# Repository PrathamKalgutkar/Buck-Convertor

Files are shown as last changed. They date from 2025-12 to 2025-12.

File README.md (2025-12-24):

Buck Convertor designed for IIT Madras's EE4102 - "Electronic Product Design" Course Project
Contained in the Repository are the KiCAD project Files, CSV file for Bill of Materials and PDF File of Final Report submitted to Course Instructor

The Project consisted of :
- Design of Buck Convertor
- Derivation of Component Values
- Design of Circuit Schematic
- Design of DRC checked PCB Board
- 3D View of the Designed PCB
- Estimation of Convertor Efficiency
- Bill of Materials

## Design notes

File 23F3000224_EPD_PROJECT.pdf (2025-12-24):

# ELECTRONIC PRODUCT DESIGN PROJECT

PRATHAM SANJEEV KALGUTKAR

23F3000224

### - Design a circuit with input 24 V DC (Assume a 24 battery) and output of +15V and 0.5 A

For the given design requirements, A buck convertor is ideal for this application, moreover, we will be using a “Jellybean”, a Widely Available and Affordable Convertor, for the design. Texas Instruments, MC34063 is ideal for our use case

Design Requirements: - Referencing the Chapter 9.2.3.1 of the Datasheet, we need to define certain design requirements given below

Vin = 24V

Vout = 15V

Iout(Max) = 0.5A

fmin = 100 kHz (Maximum Switching Frequency, refer 8.3, taken to reduce Component Values)

Vripple = ±100mV (Peak to Peak Value of desired Ripple)

Vsat = 1V (Refer 7.6 For Saturation Voltage of Darlington pair)

Vf = 0.4V (Refer Figure 13 of Diode 1N5819)

R1 = 1000 Ω

R2 = 11000Ω

Design Procedure: - Referencing Table 9.2.3.2, we need to calculate various parameters to determine the component Values

ton

toff

=

Vout + Vf

Vin(Min) − VSat − VOut

=

15 + 0.4
24 − 1 − 15 =

77
40

= 1.925

(ton + toff) =

1
f

=

1
100000 = 1 × 10⁻⁵
sec

toff =

ton + toff
ton
toff

+ 1

=

1 × 10⁻⁵
1.925 + 1

=

1
292500 = 3.418803419 × 10⁻⁶ sec

ton = (ton + toff) − toff = 1 × 10⁻⁵ −

1
292500 = 6.581196581 × 10⁻⁶

CT = 4 × 10⁻⁵

ton = 2.6323478632 × 10⁻¹⁰ F ≈ 270pF

Ipk(Switcℎ) = 2 × Iout(Max) = 2 ∗ 0.5 = 1A

Rsc =

0.3

Ipk(Switcℎ)

= 0.3 Ω

LMin = (
Vin(Min) − Vsat − Vout

Ipk(switcℎ)

) tonmax = (
24 − 1 − 15
1

) ∗ 6.581196581 × 10⁻⁶

= 5.264957265 × 10⁻⁵ ≈ 52μH ≈ 68μH (Next standard value)

Co =

Ipk(switcℎ) ∗ (ton + toff)

8Vripple(pp)

=

1 ∗ 1 × 10⁻⁵
8 ∗ 0.2

= 6.25 × 10⁻⁶ ≈ 6.8μF

Vout = 1.25 (1 +

R2
R1

) = 1.25 (1 +

11000
1000 ) = 15V

### Final Component Values

Timing Capacitor: - | CT = 270 pF
Output Capacitor: - | CO = 6.8 μF
Inductor: - | L = 68 μH
Short Circuit Resistor: - | Rsc = 0.3 Ω
Feedback Resistors: - | R1 = 1KΩ
| R2 = 11KΩ

### Schematic Diagram: -

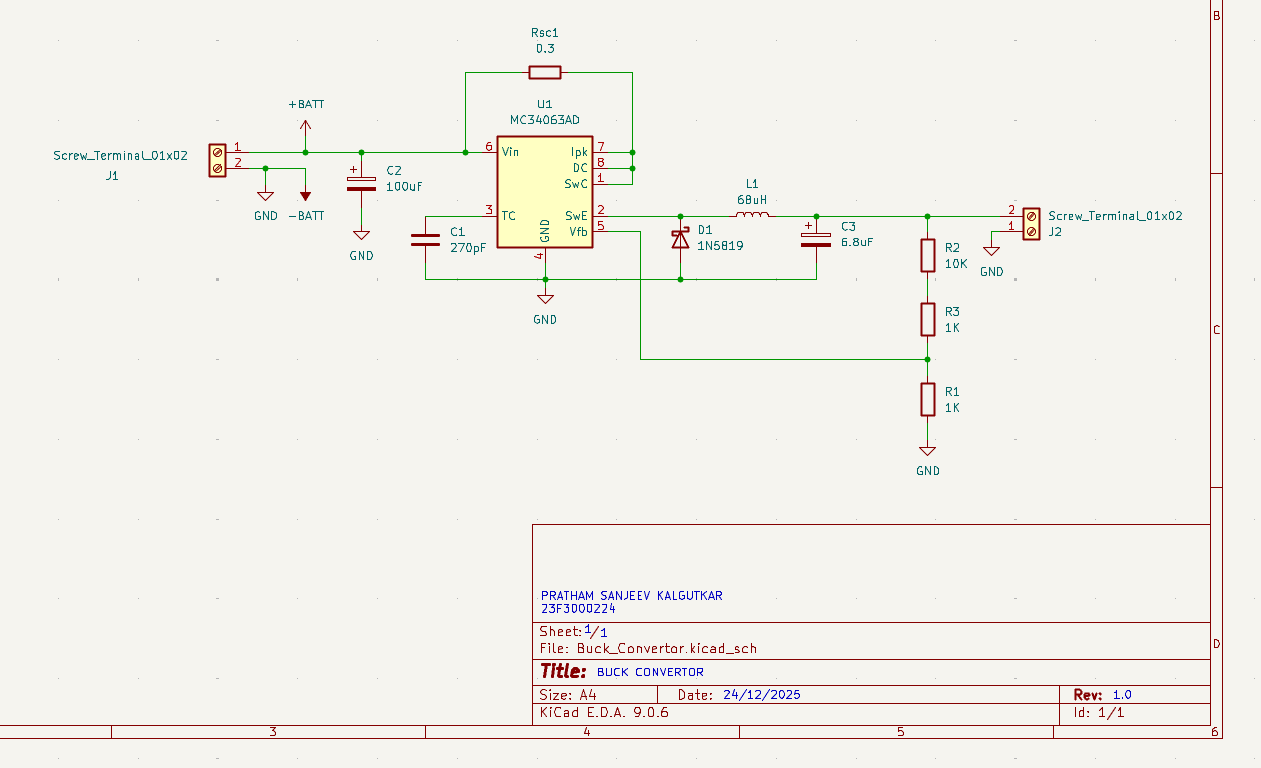
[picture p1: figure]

### PCB LAYOUT: -

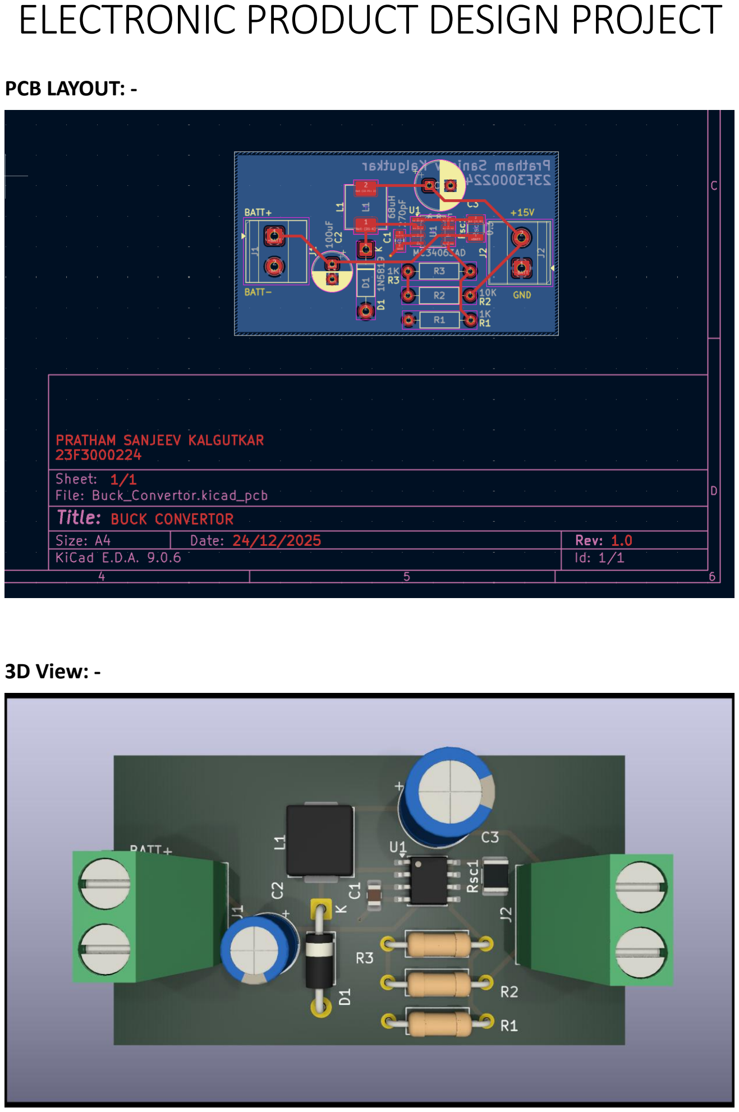
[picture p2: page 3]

### 3D View: -

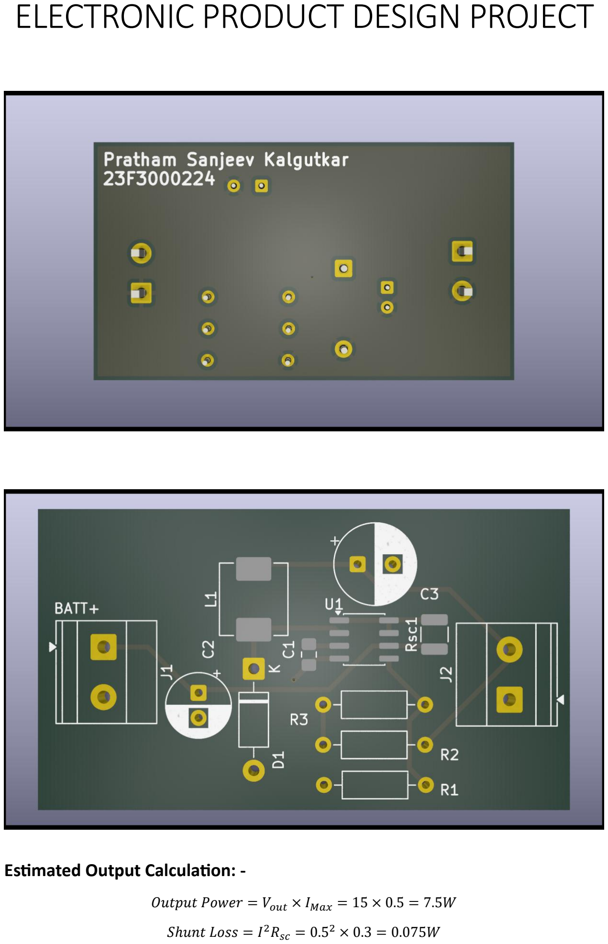
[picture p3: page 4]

### Estimated Output Calculation: -

Output Power = Vout × IMax = 15 × 0.5 = 7.5W

Sℎunt Loss = I

2Rsc = 0.5

2 × 0.3 = 0.075W

Switcℎ Conduction Loss = Iout × Vsat ×

ton
toff
ton
toff

+ 1

= 0.5 ∗ 1 ∗

1.925
1.925 + 1

=

77
234 ≈ 0.329059W

Diode Loss = Iout × Vf × (1 −

ton
toff
ton
toff

+ 1

) = 0.5 × 0.4 × (1 −
1.925
1.925 + 1

) =

6
117 ≈ 0.068W

Inductor Loss = I

2 × RDC = 0.5

2 × 0.213 = 0.05325W

Quiescent Power Draw = Vin ∗ Icc = 24 ∗ 0.004 = 0.096W

Switcℎing Loss = 0.5 × Ipk × Vin × f × trise = 0.5 × 1 × 24 × 100000 × 75ns = 0.09W

Total Loss = 0.075 +

77
234 +

6
117 + 0.05325 + 0.096 + 0.9 = 0.4558019603W

Output Power = Input Power + Total Loss = 7.5 + 0.4580419603 = 7.95580196W

Estimated Efficiency η ≈

Output Power
Input Power =

7.5
7.95580196 = 0.942708232 ≈ 94.27%

### BILL OF MATERIALS: -

# | Reference Qty Value | Datasheet Product Link | Price

1 | Rsc1 | 1 | 0.3 | ~

https://robu.in/product/0-3-ohm-3wsurface-mount-sense-resistor-pack-of-
3/#tab-description | 12
2 | R2 | 1 | 10K | ~

https://robu.in/product/10k-ohm-0-5w-
metal-film-resistor-pack-of-50/ | 0.98
3 | R1, R3 | 2 | 1K | ~

https://robu.in/product/1k-ohm-0-5w-
metal-film-resistor-pack-of-50/ | 0.98
4 | J1, J2 | 2

Screw_
Termin
al_01x0
2 | ~

https://robu.in/product/2-pin-straightpcb-screw-terminal-block-connector-3-
5mm-pitch/ | 10
5 | C3 | 1 | 6.8uF | ~

https://robu.in/product/400ax6r8mefct7 8x10-8-rubycon-6-8uf-400v-%c2%b120-plugind8xl10-8mm-aluminumelectrolytic-capacitors-leaded-rohs/#tab-
description | 13
6 | C2 | 1 | 100uF | ~

https://robu.in/product/0-3-ohm-3wsurface-mount-sense-resistor-pack-of-
3/#tab-description | 50
7 | C1 | 1 | 270pF | ~

https://robu.in/product/c0805c271j5gac tu-kemet-smd-multilayer-ceramiccapacitor-270-pf-50-v-0805-2012-metric-
%c2%b1-5-c0g-np0-c-series-kemet/ | 1.83

8 | D1 | 1 | 1N5819

https://w
ww.st.com
/resource/
en/datash
eet/1n581
9.pdf

https://robu.in/product/1n5819-1w-
diode-pack-of-30/ | 2.67
9 | L1 | 1 | 68uH

https://pr
oducts.su
mida.com
/products/
pdf/CDRH
104R_202
403.pdf?t
=1766595
187

https://robu.in/product/cdrh104r-68%ce%bch-power-inductor-pack-of-
5/#tab-specification | 15
10 | U1 | 1

MC340
63AD

http://ww
w.onsemi.
com/pub_
link/Collat
eral/MC34
063A-D.PDF

https://robu.in/product/mc34063adtexas-instruments-adjustable-1-25v40v-3v40v-1-5a-soic-8-dc-dc-converters-
rohs/ | 43
12 | 149.46

### KiCAD Files can be accessed from here

### https://github.com/PrathamKalgutkar/Buck-Convertor

### EOF

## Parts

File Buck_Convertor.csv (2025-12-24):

# | Reference | Qty | Value | Datasheet | Product Link | Price
1 | Rsc1 | 1 | 0.3 | ~ | https://robu.in/product/0-3-ohm-3w-surface-mount-sense-resistor-pack-of-3/#tab-description | 12
2 | R2 | 1 | 10K | ~ | https://robu.in/product/10k-ohm-0-5w-metal-film-resistor-pack-of-50/ | 0.98
3 | R1,R3 | 2 | 1K | ~ | https://robu.in/product/1k-ohm-0-5w-metal-film-resistor-pack-of-50/ | 0.98
4 | J1,J2 | 2 | Screw_Terminal_01x02 | ~ | https://robu.in/product/2-pin-straight-pcb-screw-terminal-block-connector-3-5mm-pitch/ | 10
5 | C3 | 1 | 6.8uF | ~ | https://robu.in/product/400ax6r8mefct78x10-8-rubycon-6-8uf-400v-%c2%b120-plugind8xl10-8mm-aluminum-electrolytic-capacitors-leaded-rohs/ | 13
6 | C2 | 1 | 100uF | ~ | https://robu.in/product/0-3-ohm-3w-surface-mount-sense-resistor-pack-of-3/#tab-description | 50
7 | C1 | 1 | 270pF | ~ | https://robu.in/product/c0805c271j5gactu-kemet-smd-multilayer-ceramic-capacitor-270-pf-50-v-0805-2012-metric-%c2%b1-5-c0g-np0-c-series-kemet/ | 1.83
8 | D1 | 1 | 1N5819 | https://www.st.com/resource/en/datasheet/1n5819.pdf | https://robu.in/product/1n5819-1w-diode-pack-of-30/ | 2.67
9 | L1 | 1 | 68uH | https://products.sumida.com/products/pdf/CDRH104R_202403.pdf?t=1766595187 | https://robu.in/product/cdrh104r-68%ce%bch-power-inductor-pack-of-5/#tab-specification | 15
10 | U1 | 1 | MC34063AD | http://www.onsemi.com/pub_link/Collateral/MC34063A-D.PDF | https://robu.in/product/mc34063ad-texas-instruments-adjustable-1-25v40v-3v40v-1-5a-soic-8-dc-dc-converters-rohs/ | 43
 |  | 12 |  |  |  | 149.46

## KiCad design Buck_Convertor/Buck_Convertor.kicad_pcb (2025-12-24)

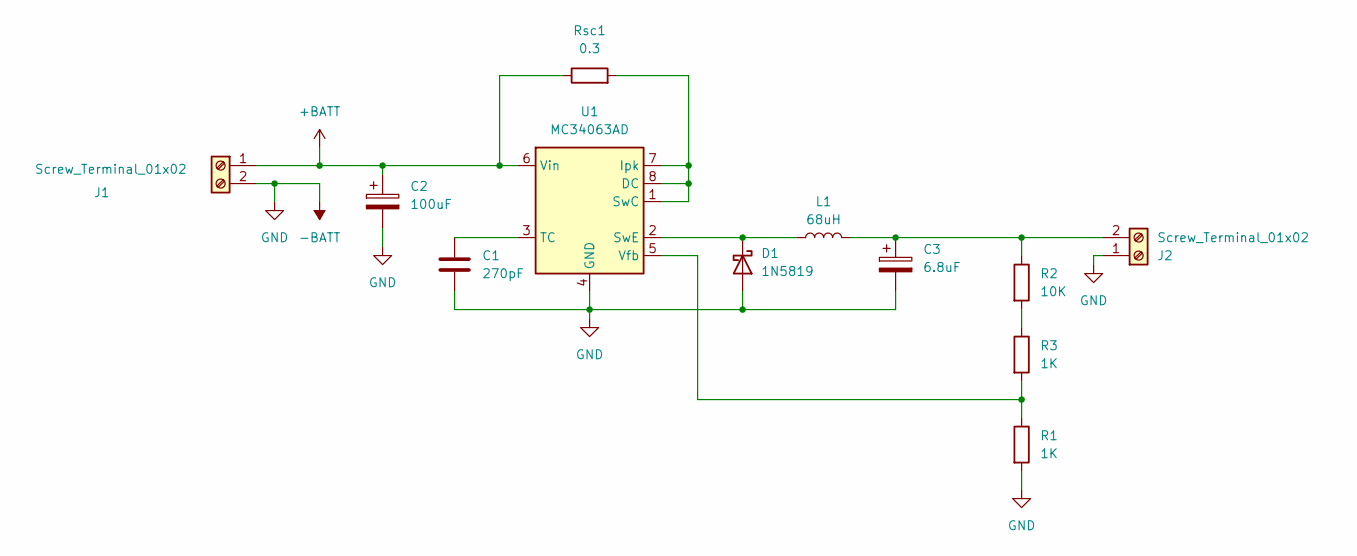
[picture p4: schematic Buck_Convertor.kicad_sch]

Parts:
C1: 270pF; C_0805_2012Metric_Pad1.18x1.45mm_HandSolder
C2: 100uF; CP_Radial_D6.3mm_P2.50mm
C3: 6.8uF; CP_Radial_D8.0mm_P3.50mm
D1: 1N5819; D_DO-41_SOD81_P10.16mm_Horizontal
J1, J2: Screw_Terminal_01x02; TerminalBlock_Phoenix_MKDS-1,5-2_1x02_P5.00mm_Horizontal
L1: 68uH; L_Sunlord_MWSA0624S
R1, R3: 1K; R_Axial_DIN0207_L6.3mm_D2.5mm_P10.16mm_Horizontal
R2: 10K; R_Axial_DIN0207_L6.3mm_D2.5mm_P10.16mm_Horizontal
Rsc1: 0.3; R_1210_3225Metric
U1: MC34063AD; SOIC-8_3.9x4.9mm_P1.27mm

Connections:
+BATT: C2.1, J1.1, Rsc1.1, U1.6 (Vin)
-BATT: C1.2, C2.2, C3.2, D1.2 (A), J1.2, J2.1, R1.2, U1.4 (GND)
unnamed: D1.1 (K), L1.1, U1.2 (SwE)
unnamed: C3.1, J2.2, L1.2, R2.1
unnamed: R2.2, R3.1
unnamed: Rsc1.2, U1.1 (SwC), U1.7 (Ipk), U1.8 (DC)
unnamed: C1.1, U1.3 (TC)
unnamed: R1.1, R3.2, U1.5 (Vfb)

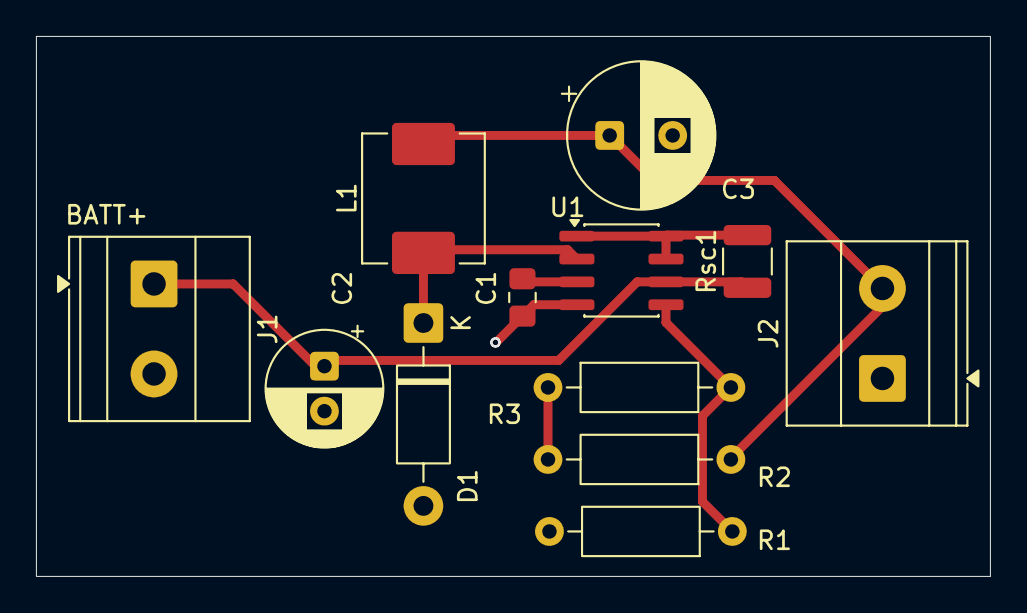
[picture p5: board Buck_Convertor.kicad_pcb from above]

Board: 2 copper layers, 53.0 x 30.0 mm, 12 parts (0 on the bottom side), 8 nets.

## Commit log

2025-12-24 KiCAD Files
    Project, Scheamtic and Board Files for the KiCAD Project
    [Buck_Convertor.kicad_pcb, Buck_Convertor.kicad_sch]
2025-12-24 BOM File
    [Buck_Convertor.csv]
